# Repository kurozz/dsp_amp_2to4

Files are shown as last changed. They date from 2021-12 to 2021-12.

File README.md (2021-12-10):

DSP Amplifier - 2 inputs 4 outputs
Amplifier with DSP based on TPA3116D2 and ADAU1701 with 4 outputs and stereo input.

DSP programming can be done with SigmaStudio and needs an appropriate programmer.
How to program: https://daumemo.com/how-to-program-an-analog-devices-dsp/

Hackaday.io: https://hackaday.io/project/182993-dsp-amplifier-2-inputs-4-outputs
Project at PCBWAY (I get some credits if you buy the PCB from this link): https://www.pcbway.com/project/shareproject/DSP_Amplifier___2_inputs_4_outputs.html

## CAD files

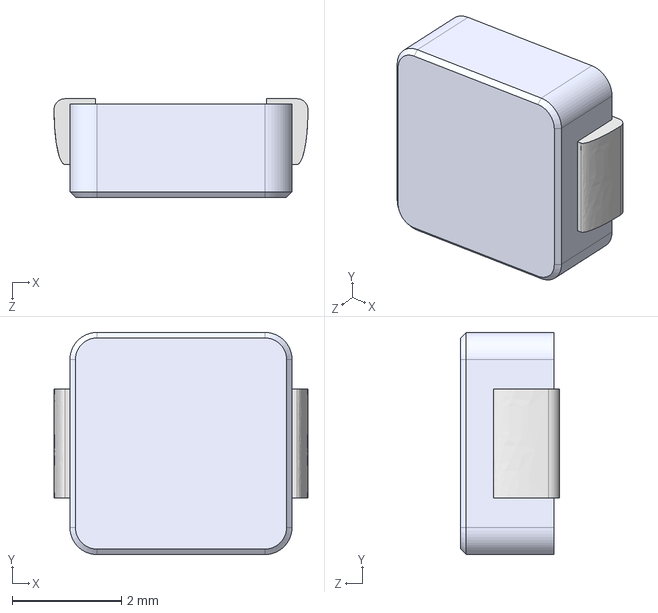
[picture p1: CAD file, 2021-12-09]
3D/WE_Inductor_4020.STEP
4.64 x 4.06 x 1.80 mm

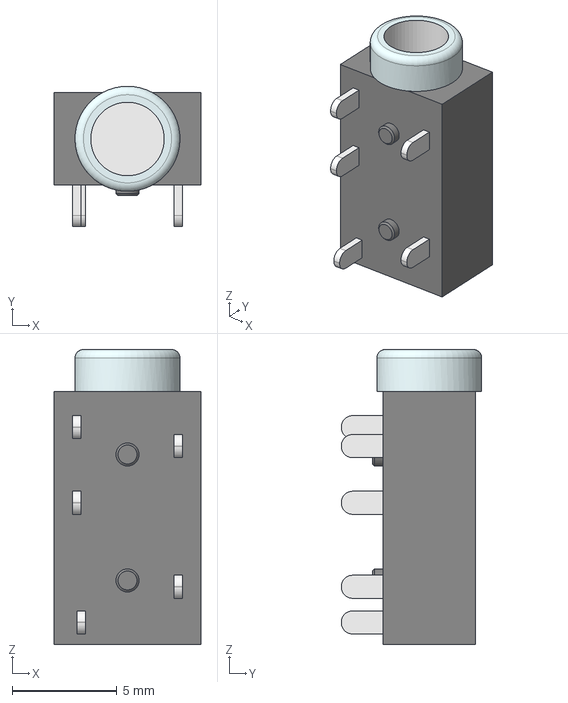
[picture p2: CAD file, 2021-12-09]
3D/PJ-3720.step
7.00 x 6.69 x 14.1 mm

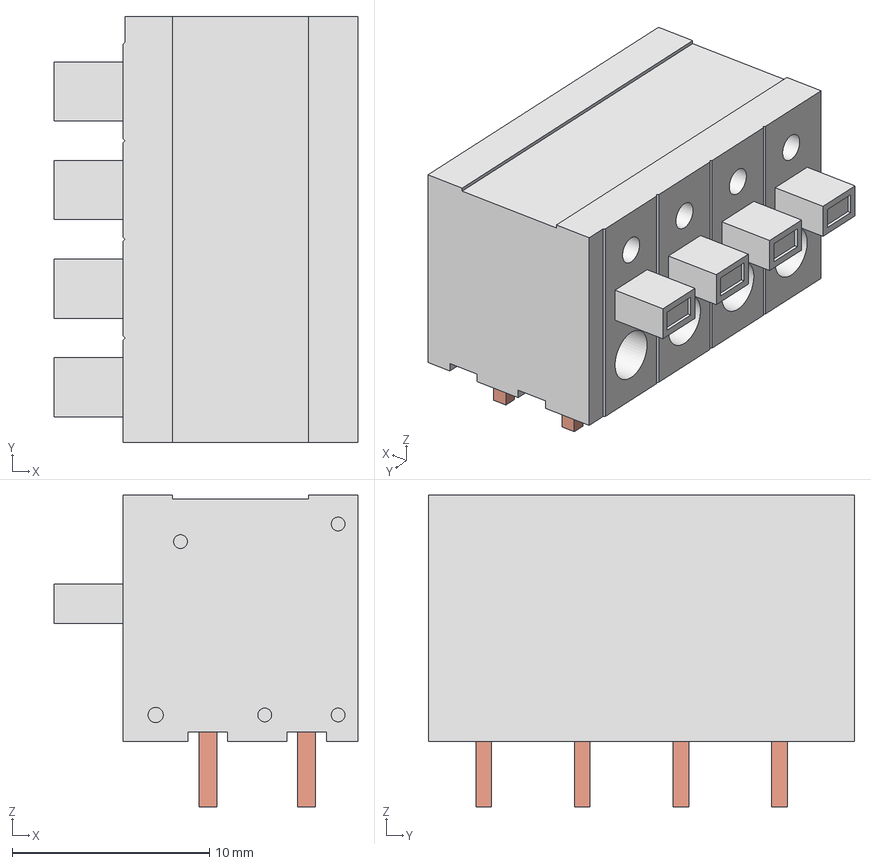
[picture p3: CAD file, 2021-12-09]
3D/KF211R.stp
15.4 x 21.6 x 15.8 mm

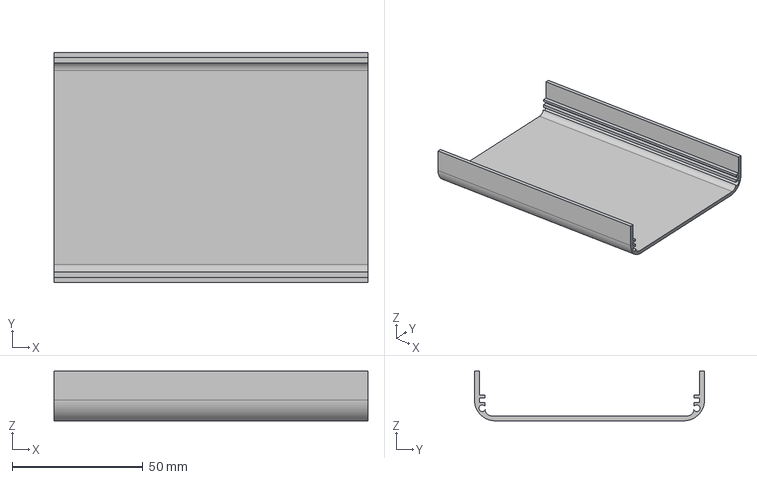
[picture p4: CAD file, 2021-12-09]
3D/aluminum_enclosure_88x38.step
120.0 x 88.0 x 19.0 mm

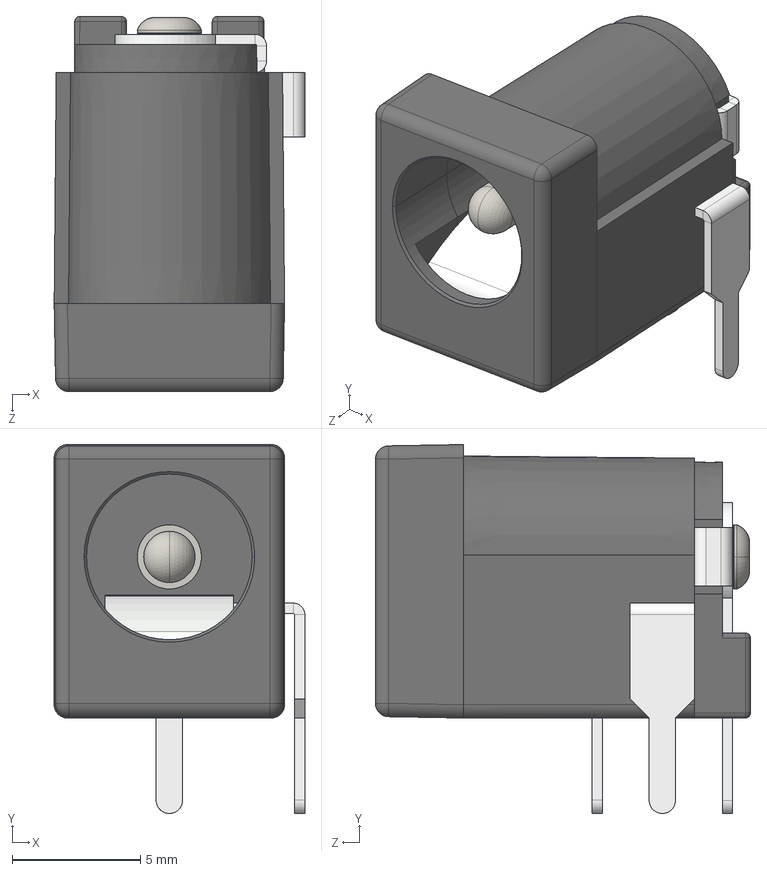
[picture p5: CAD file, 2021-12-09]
3D/DC Power Jack 5.5mm x 2.1mm.STEP
9.77 x 14.4 x 14.6 mm

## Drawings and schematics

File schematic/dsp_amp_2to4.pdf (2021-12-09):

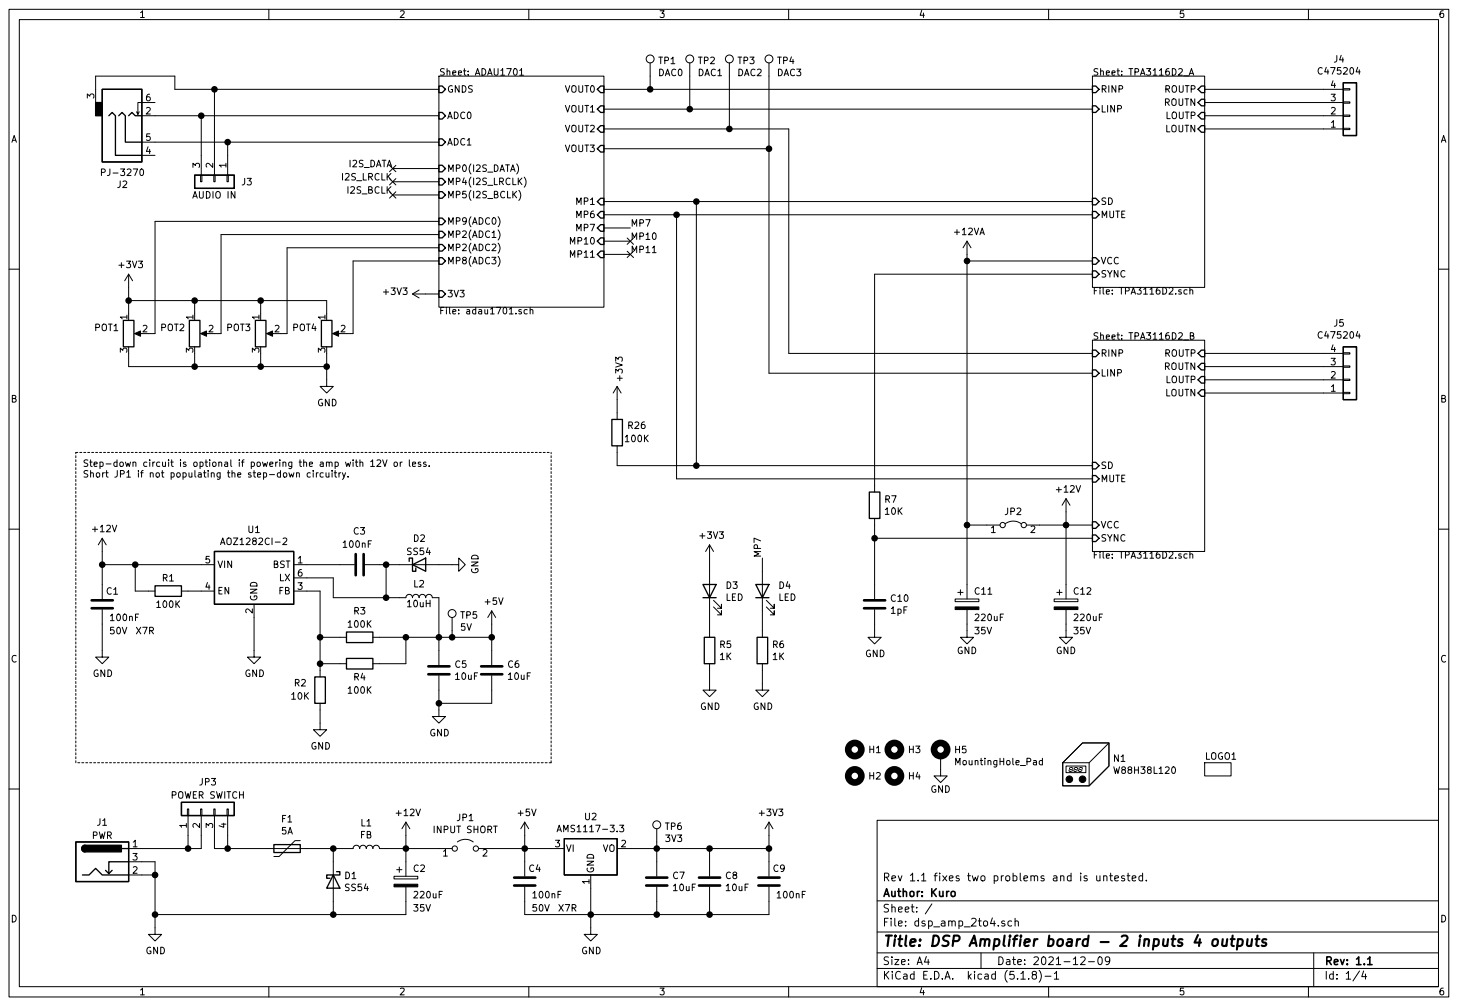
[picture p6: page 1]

File: TPA3116D2.sch SYNC MUTE

Step-down circuit is optional if powering the amp with 12V or less.
Short JP1 if not populating the step-down circuitry.

File: dsp_amp_2to4.sch Sheet: / Author: Kuro Rev 1.1 fixes two problems and is untested.

Id: 1/4 Title: DSP Amplifier board - 2 inputs 4 outputs

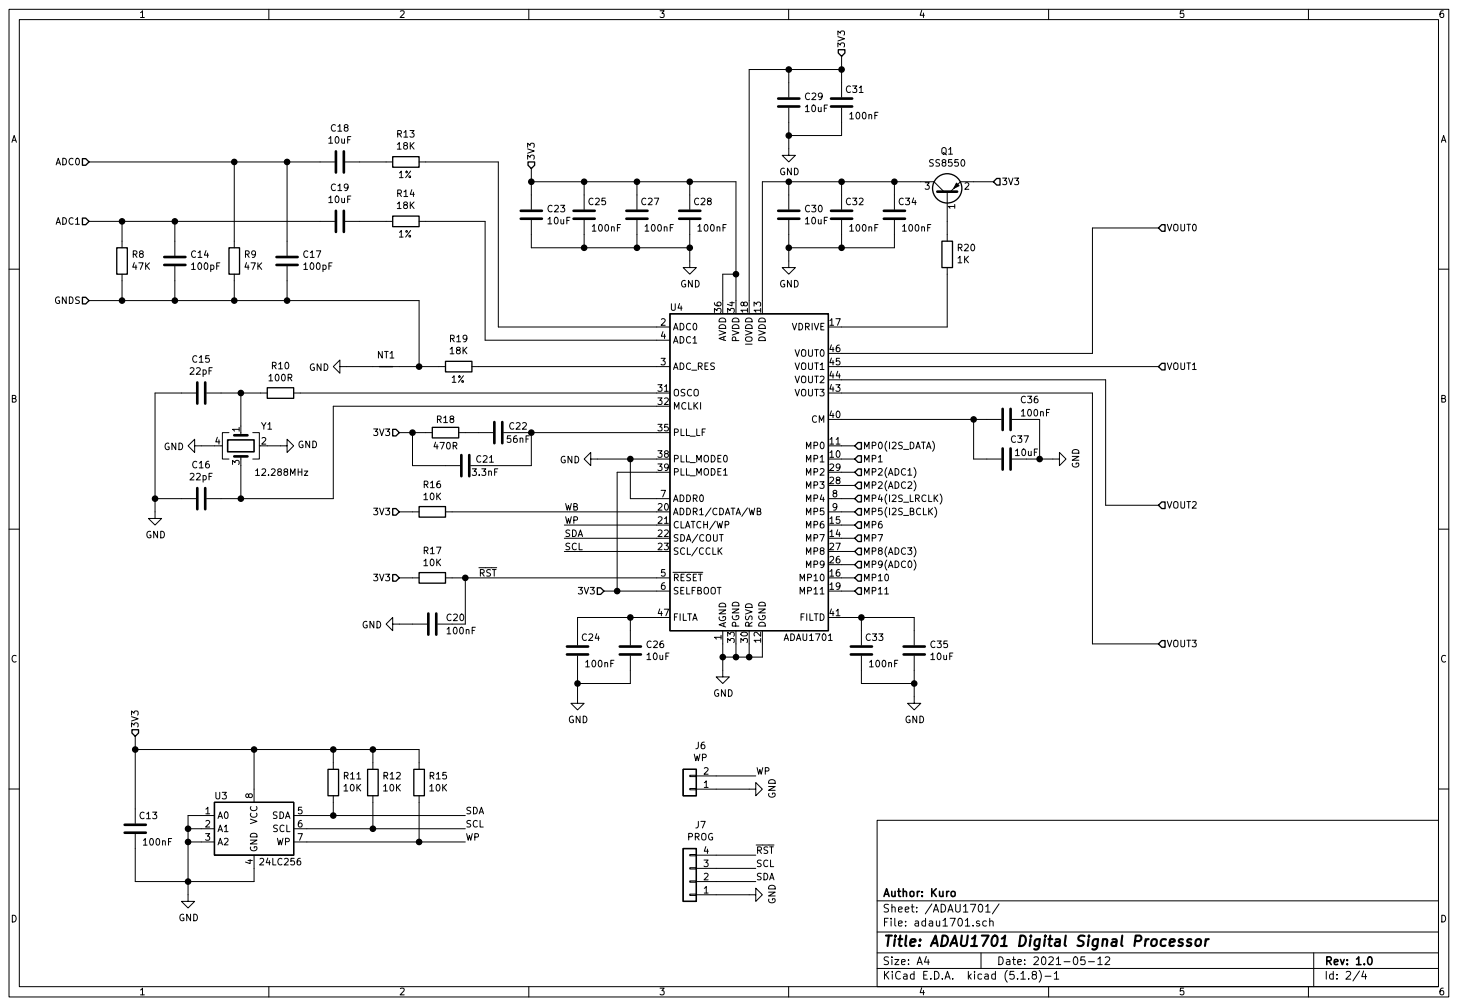
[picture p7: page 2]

Id: 2/4 Title: ADAU1701 Digital Signal Processor File: adau1701.sch Sheet: /ADAU1701/ Author: Kuro R11

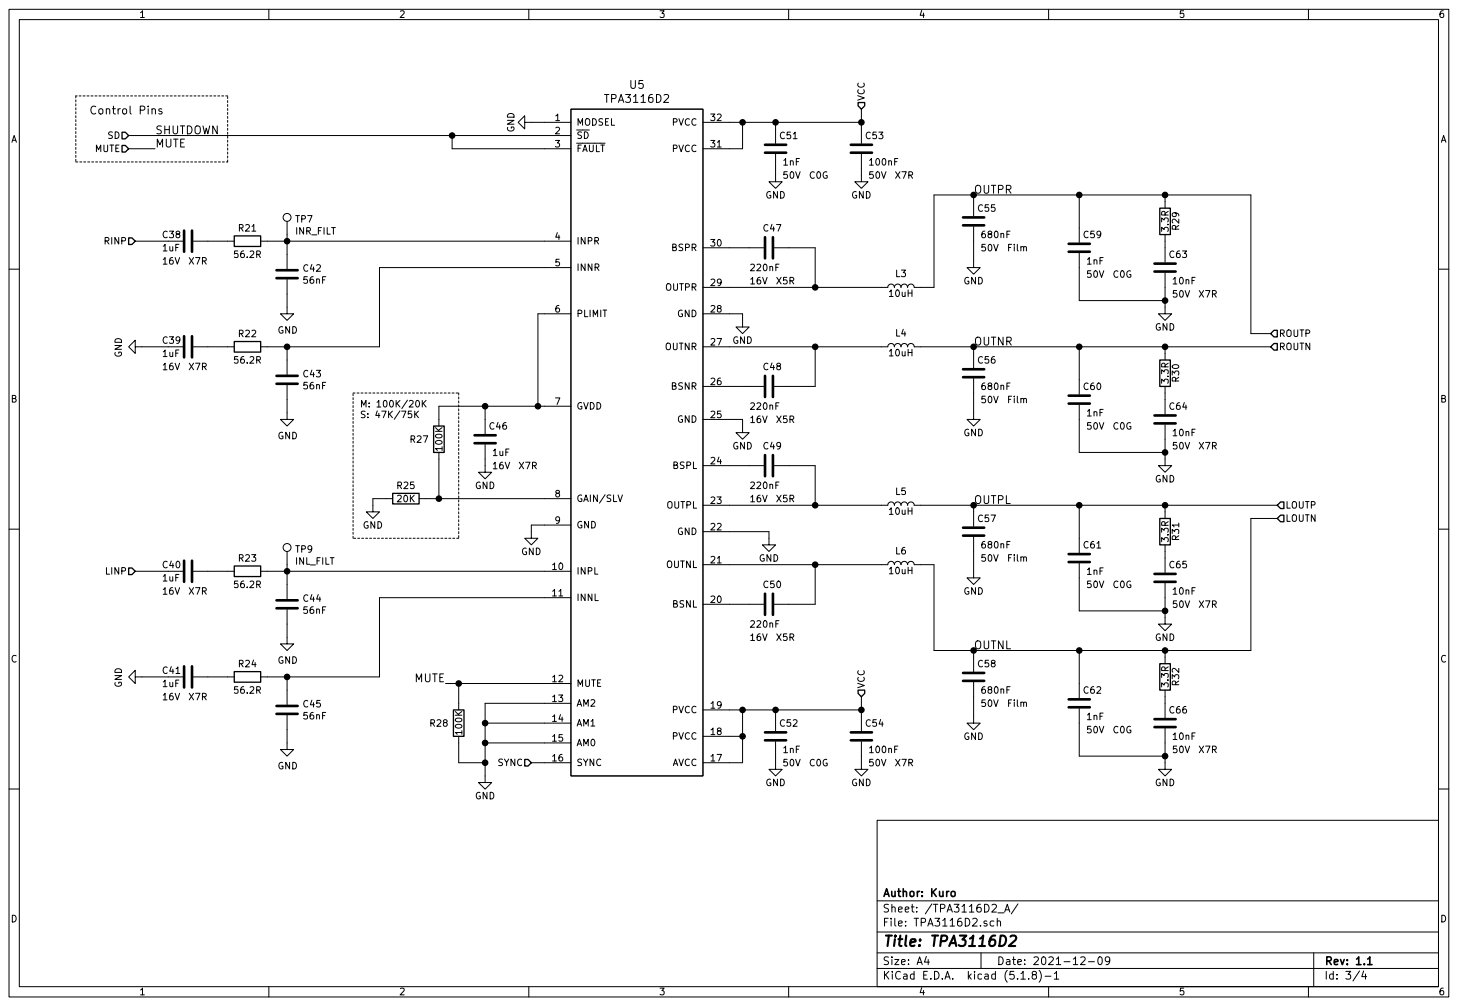
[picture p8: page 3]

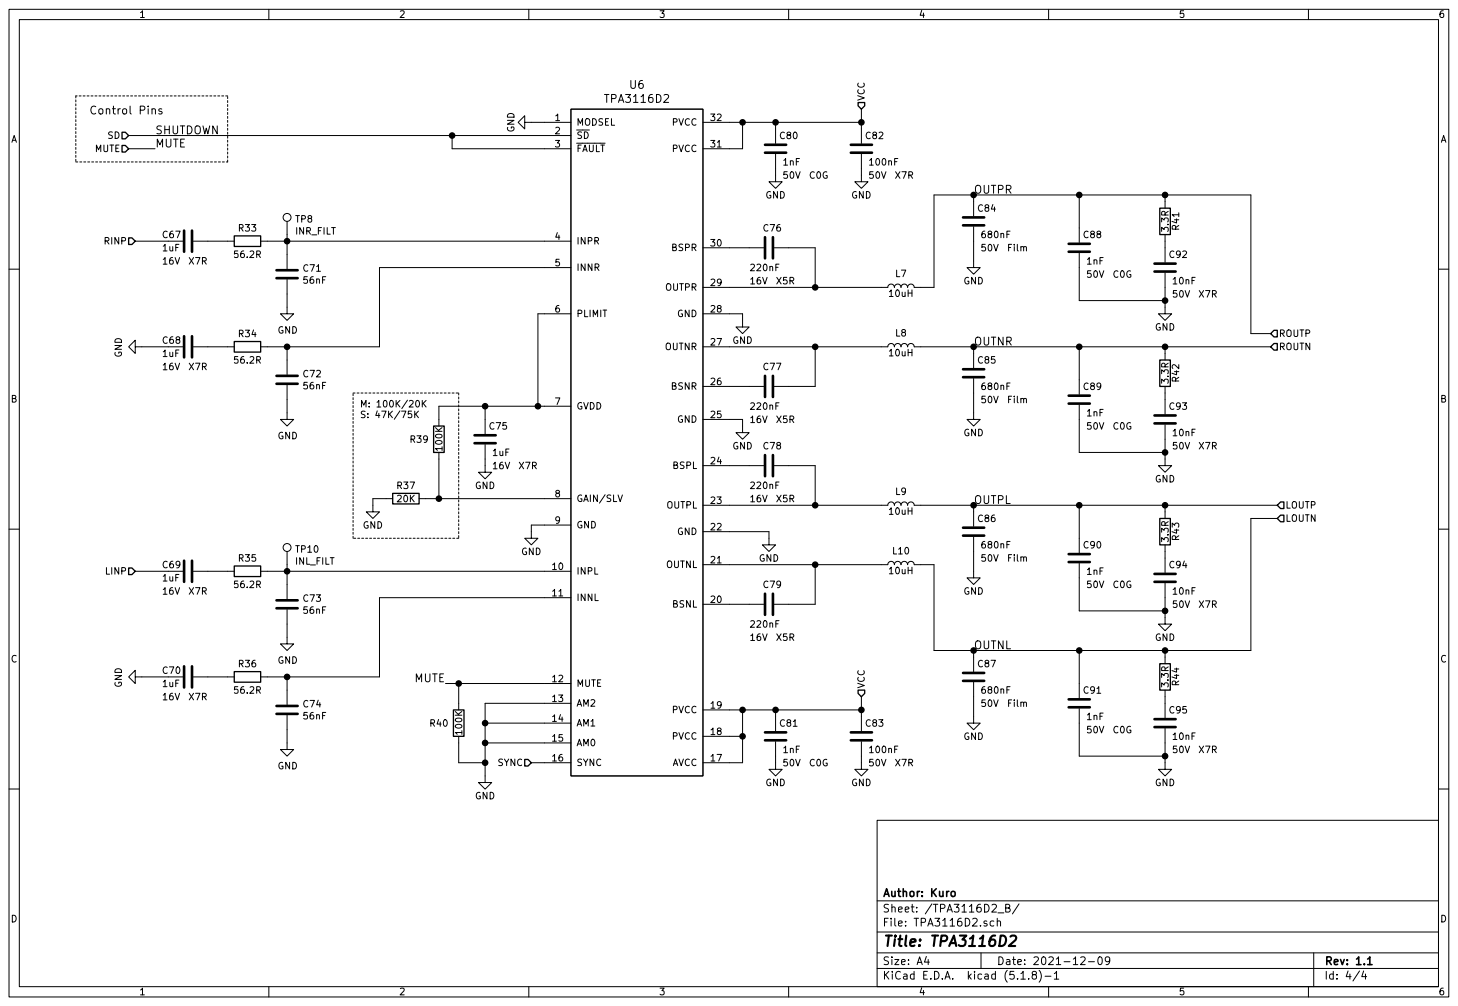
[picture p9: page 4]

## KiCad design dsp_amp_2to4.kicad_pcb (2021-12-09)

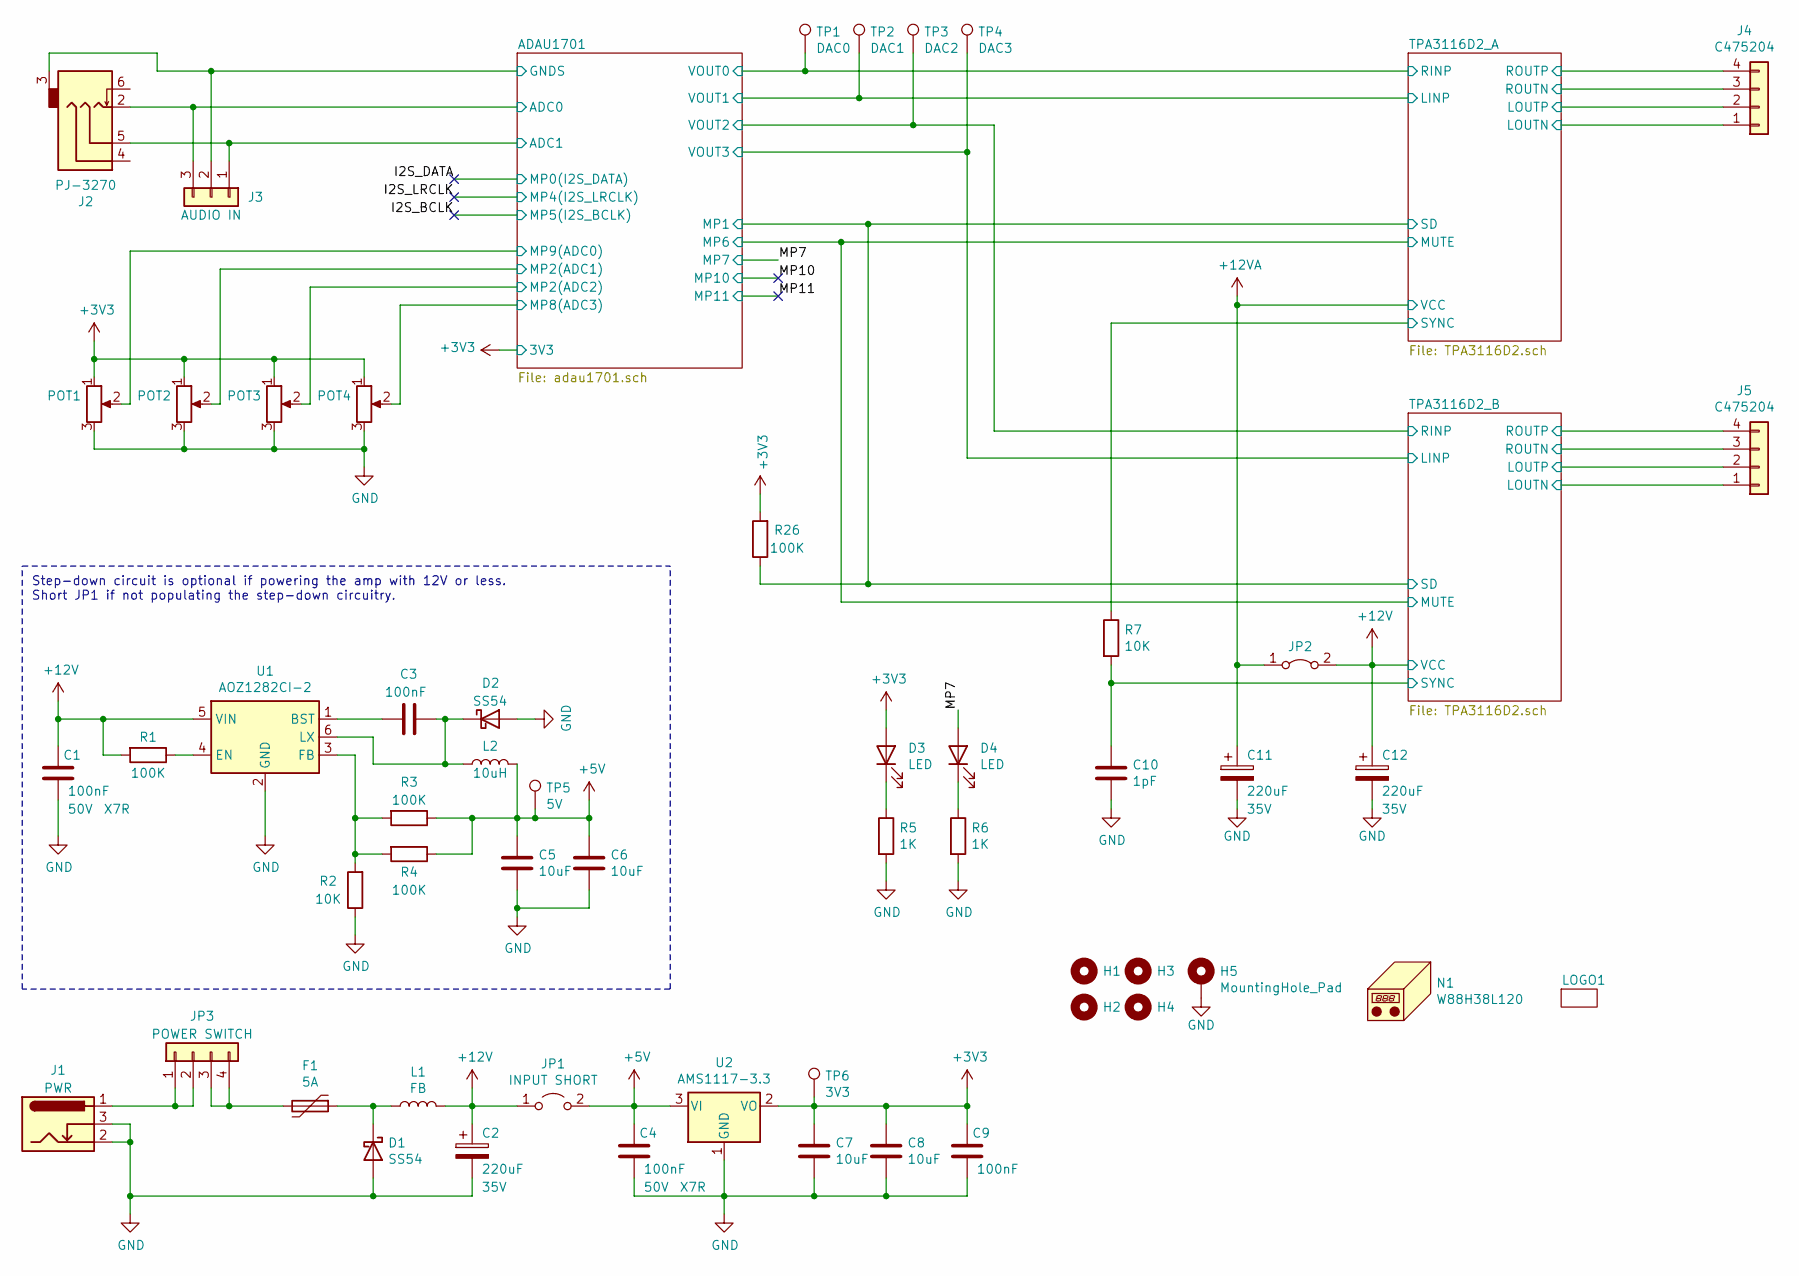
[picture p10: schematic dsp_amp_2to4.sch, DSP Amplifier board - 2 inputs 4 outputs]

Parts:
C1, C3, C4, C9: 100nF; C_0603_1608Metric; Rating X7R; Voltage 50V; LCSC Part Number C14663
C2, C11, C12: 220uF; CP_Radial_D8.0mm_P3.50mm; Voltage 35V; LCSC Part Number C433284
C5, C6, C7, C8: 10uF; C_0603_1608Metric; LCSC Part Number C85713
C10: 1pF; C_0603_1608Metric
D1, D2: SS54; D_SMA; LCSC Part Number C908681
D3, D4: LED; LED_D3.0mm; LCSC Part Number C710207
F1: 5A; Fuse_1206_3216Metric; LCSC Part Number C99541
H1, H2, H3, H4: MountingHole; MountingHole_3.2mm_M3
H5: MountingHole_Pad; MountingHole_3.2mm_M3_Pad_Via
J1: PWR; C381116; LCSC Part Number C381116
J2: PJ-3270; LCSC Part Number C381134
J3: JST XH-B3B; JST_XH_B3B-XH-A_1x03_P2.50mm_Vertical; LCSC Part Number C2316
J4, J5: C475204; LCSC Part Number C475204
JP1: INPUT SHORT; SolderJumper-2_P1.3mm_Open_TrianglePad1.0x1.5mm
JP2: Jumper Wire; R_Axial_DIN0204_L3.6mm_D1.6mm_P7.62mm_Horizontal
JP3: POWER SWITCH; JST_XH_B4B-XH-A_1x04_P2.50mm_Vertical
L1: FB; L_0805_2012Metric; LCSC Part Number C304323
L2: 10uH; L_6.3x6.3_H3; LCSC Part Number C207842
LOGO1: logo; shamiko
N1: W88H38L120; Aluminum_W88H38L120
POT1, POT2, POT3, POT4: JST XH-B3B; JST_XH_B3B-XH-A_1x03_P2.50mm_Vertical; LCSC Part Number C2316
R1, R3, R4, R26: 100K; R_0603_1608Metric; LCSC Part Number C14675
R2, R7: 10K; R_0603_1608Metric; LCSC Part Number C98220
R5, R6: 1K; R_0603_1608Metric; LCSC Part Number C22548
TP1: DAC0; TestPoint_THTPad_D1.0mm_Drill0.5mm
TP2: DAC1; TestPoint_THTPad_D1.0mm_Drill0.5mm
TP3: DAC2; TestPoint_THTPad_D1.0mm_Drill0.5mm
TP4: DAC3; TestPoint_THTPad_D1.0mm_Drill0.5mm
TP5: 5V; TestPoint_THTPad_D1.0mm_Drill0.5mm
TP6: 3V3; TestPoint_THTPad_D1.0mm_Drill0.5mm
U1: AOZ1282CI-2; SOT-23-6; LCSC Part Number C176766
U2: AMS1117-3.3; SOT-223-3_TabPin2; LCSC Part Number C347222

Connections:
+3V3: C7.1, C8.1, C9.1, D3.2 (A), POT1.1, POT2.1, POT3.1, POT4.1, R26.2, TP6.1, U2.2 (VO); also elsewhere on the board
+5V: C4.1, C5.1, C6.1, JP1.2 (B), L2.2, R3.1, R4.1, TP5.1, U2.3 (VI)
+12V: C1.1, C2.1, C12.1, JP1.1 (A), JP2.2 (B), L1.2, R1.2, U1.5 (VIN); also elsewhere on the board
+12VA: C11.1, JP2.1 (A); also elsewhere on the board
/ADAU1701/ADC0: J2.2, J3.3; also elsewhere on the board
/ADAU1701/ADC1: J2.5, J3.1; also elsewhere on the board
/ADAU1701/GNDS: J2.3, J3.2; also elsewhere on the board
/ADAU1701/MP1: R26.1; also elsewhere on the board
/ADAU1701/MP2(ADC1): POT2.2; also elsewhere on the board
/ADAU1701/MP2(ADC2): POT3.2; also elsewhere on the board
/ADAU1701/MP8(ADC3): POT4.2; also elsewhere on the board
/ADAU1701/MP9(ADC0): POT1.2; also elsewhere on the board
/MP7: D4.2 (A); also elsewhere on the board
/TPA3116D2_A/LINP: TP2.1; also elsewhere on the board
/TPA3116D2_A/LOUTN: J4.1; also elsewhere on the board
/TPA3116D2_A/LOUTP: J4.2; also elsewhere on the board
/TPA3116D2_A/RINP: TP1.1; also elsewhere on the board
/TPA3116D2_A/ROUTN: J4.3; also elsewhere on the board
/TPA3116D2_A/ROUTP: J4.4; also elsewhere on the board
/TPA3116D2_A/SYNC: R7.1; also elsewhere on the board
/TPA3116D2_B/LINP: TP4.1; also elsewhere on the board
/TPA3116D2_B/LOUTN: J5.1; also elsewhere on the board
/TPA3116D2_B/LOUTP: J5.2; also elsewhere on the board
/TPA3116D2_B/RINP: TP3.1; also elsewhere on the board
/TPA3116D2_B/ROUTN: J5.3; also elsewhere on the board
/TPA3116D2_B/ROUTP: J5.4; also elsewhere on the board
/TPA3116D2_B/SYNC: C10.1, R7.2; also elsewhere on the board
GND: C1.2, C2.2, C4.2, C5.2, C6.2, C7.2, C8.2, C9.2, C10.2, C11.2, C12.2, D1.2 (A), D2.2 (A), H5.1, J1.2, J1.3, POT1.3, POT2.3, POT3.3, POT4.3, R2.1, R5.2, R6.2, U1.2 (GND), U2.1 (GND); also elsewhere on the board
unnamed: C3.1, U1.1 (BST)
unnamed: C3.2, D2.1 (K), L2.1, U1.6 (LX)
unnamed: D1.1 (K), F1.1, L1.1
unnamed: D3.1 (K), R5.1
unnamed: D4.1 (K), R6.1
unnamed: F1.2, JP3.3, JP3.4
unnamed: J1.1, JP3.1, JP3.2
unnamed: R1.1, U1.4 (EN)
unnamed: R2.2, R3.2, R4.2, U1.3 (FB)

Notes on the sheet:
Step-down circuit is optional if powering the amp with 12V or less. Short JP1 if not populating the step-down circuitry.

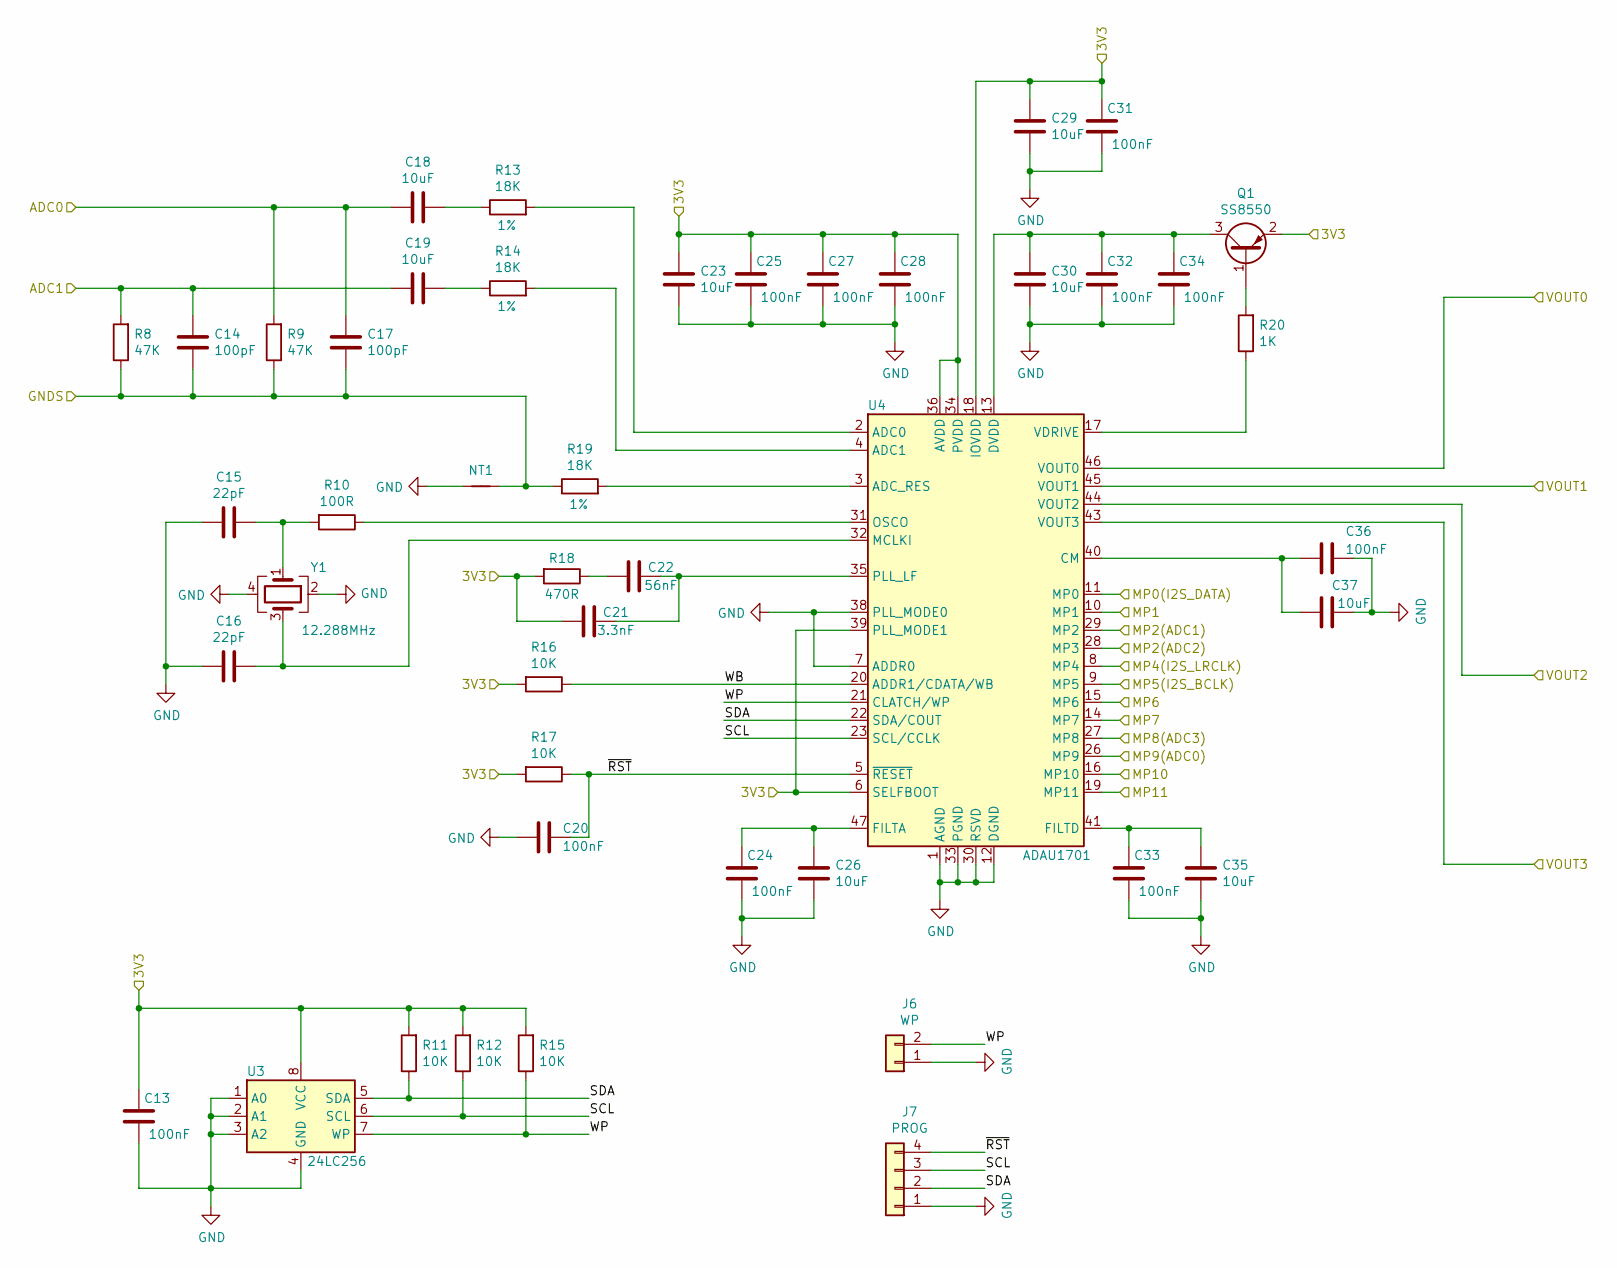
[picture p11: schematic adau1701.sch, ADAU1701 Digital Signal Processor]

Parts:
C13, C20, C24, C25, C27, C28, C31, C32, C33, C34, C36: 100nF; C_0603_1608Metric; Rating X7R; Voltage 50V; LCSC Part Number C14663
C14, C17: 100pF; C_0603_1608Metric; LCSC Part Number C14665
C15, C16: 22pF; C_0603_1608Metric; LCSC Part Number C105620
C18, C19, C23, C26, C29, C30, C35, C37: 10uF; C_0603_1608Metric; LCSC Part Number C85713
C21: 3.3nF; C_0603_1608Metric; LCSC Part Number C107088
C22: 56nF; C_0603_1608Metric; LCSC Part Number C282072
J6: WP; PinHeader_1x02_P2.54mm_Vertical
J7: PROG; PinHeader_1x04_P2.54mm_Vertical
NT1: Net-Tie_2; NetTie-2_SMD_Pad0.5mm
Q1: SS8550; SOT-23; LCSC Part Number C545534
R8, R9: 47K; R_0603_1608Metric; LCSC Part Number C105579
R10: 100R; R_0603_1608Metric; LCSC Part Number C105588
R11, R12, R15, R16, R17: 10K; R_0603_1608Metric; LCSC Part Number C98220
R13, R14, R19: 18K; R_0603_1608Metric; Tolerance 1%; LCSC Part Number C114610
R18: 470R; R_0603_1608Metric; LCSC Part Number C114669
R20: 1K; R_0603_1608Metric; LCSC Part Number C22548
U3: 24LC256; SOIC-8_3.9x4.9mm_P1.27mm; LCSC Part Number C5458
U4: ADAU1701; LQFP-48_7x7mm_P0.5mm; LCSC Part Number C389590
Y1: 12.288MHz; Crystal_SMD_SeikoEpson_FA238-4Pin_3.2x2.5mm; LCSC Part Number C389826

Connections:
+3V3: C13.1, C21.2, C23.1, C25.1, C27.1, C28.1, C29.1, C31.1, Q1.2 (E), R11.2, R12.2, R15.2, R16.2, R17.2, R18.2, U3.8 (VCC), U4.6 (SELFBOOT), U4.18 (IOVDD), U4.34 (PVDD), U4.36 (AVDD), U4.39 (PLL_MODE1), U4.48 (AVDD); also elsewhere on the board
/ADAU1701/ADC0: C17.2, C18.1, R9.2; also elsewhere on the board
/ADAU1701/ADC1: C14.2, C19.1, R8.2; also elsewhere on the board
/ADAU1701/GNDS: C14.1, C17.1, NT1.2, R8.1, R9.1, R19.1; also elsewhere on the board
/ADAU1701/MP1: U4.10 (MP1); also elsewhere on the board
/ADAU1701/MP2(ADC1): U4.29 (MP2); also elsewhere on the board
/ADAU1701/MP2(ADC2): U4.28 (MP3); also elsewhere on the board
/ADAU1701/MP6: U4.15 (MP6); also elsewhere on the board
/ADAU1701/MP8(ADC3): U4.27 (MP8); also elsewhere on the board
/ADAU1701/MP9(ADC0): U4.26 (MP9); also elsewhere on the board
/ADAU1701/SCL: J7.3, R12.1, U3.6 (SCL), U4.23 (SCL/CCLK)
/ADAU1701/SDA: J7.2, R11.1, U3.5 (SDA), U4.22 (SDA/COUT)
/ADAU1701/WB: R16.1, U4.20 (ADDR1/CDATA/WB)
/ADAU1701/WP: J6.2, R15.1, U3.7 (WP), U4.21 (CLATCH/WP)
/ADAU1701/~RST: C20.1, J7.4, R17.1, U4.5 (~RESET)
/I2S_BCLK: U4.9 (MP5)
/I2S_DATA: U4.11 (MP0)
/I2S_LRCLK: U4.8 (MP4)
/MP7: U4.14 (MP7); also elsewhere on the board
/MP10: U4.16 (MP10)
/MP11: U4.19 (MP11)
/TPA3116D2_A/LINP: U4.45 (VOUT1); also elsewhere on the board
/TPA3116D2_A/RINP: U4.46 (VOUT0); also elsewhere on the board
/TPA3116D2_B/LINP: U4.43 (VOUT3); also elsewhere on the board
/TPA3116D2_B/RINP: U4.44 (VOUT2); also elsewhere on the board
GND: C13.2, C15.1, C16.1, C20.2, C23.2, C24.2, C25.2, C26.2, C27.2, C28.2, C29.2, C30.2, C31.2, C32.2, C33.2, C34.2, C35.2, C36.1, C37.1, J6.1, J7.1, NT1.1, U3.1 (A0), U3.2 (A1), U3.3 (A2), U3.4 (GND), U4.1 (AGND), U4.7 (ADDR0), U4.12 (DGND), U4.25 (DGND), U4.30 (RSVD), U4.33 (PGND), U4.37 (AGND), U4.38 (PLL_MODE0), U4.42 (AGND), Y1.2, Y1.4; also elsewhere on the board
unnamed: C15.2, R10.2, Y1.1
unnamed: C16.2, U4.32 (MCLKI), Y1.3
unnamed: C18.2, R13.1
unnamed: C19.2, R14.1
unnamed: C21.1, C22.1, U4.35 (PLL_LF)
unnamed: C22.2, R18.1
unnamed: C24.1, C26.1, U4.47 (FILTA)
unnamed: C30.1, C32.1, C34.1, Q1.3 (C), U4.13 (DVDD), U4.24 (DVDD)
unnamed: C33.1, C35.1, U4.41 (FILTD)
unnamed: C36.2, C37.2, U4.40 (CM)
unnamed: Q1.1 (B), R20.2
unnamed: R10.1, U4.31 (OSCO)
unnamed: R13.2, U4.2 (ADC0)
unnamed: R14.2, U4.4 (ADC1)
unnamed: R19.2, U4.3 (ADC_RES)
unnamed: R20.1, U4.17 (VDRIVE)

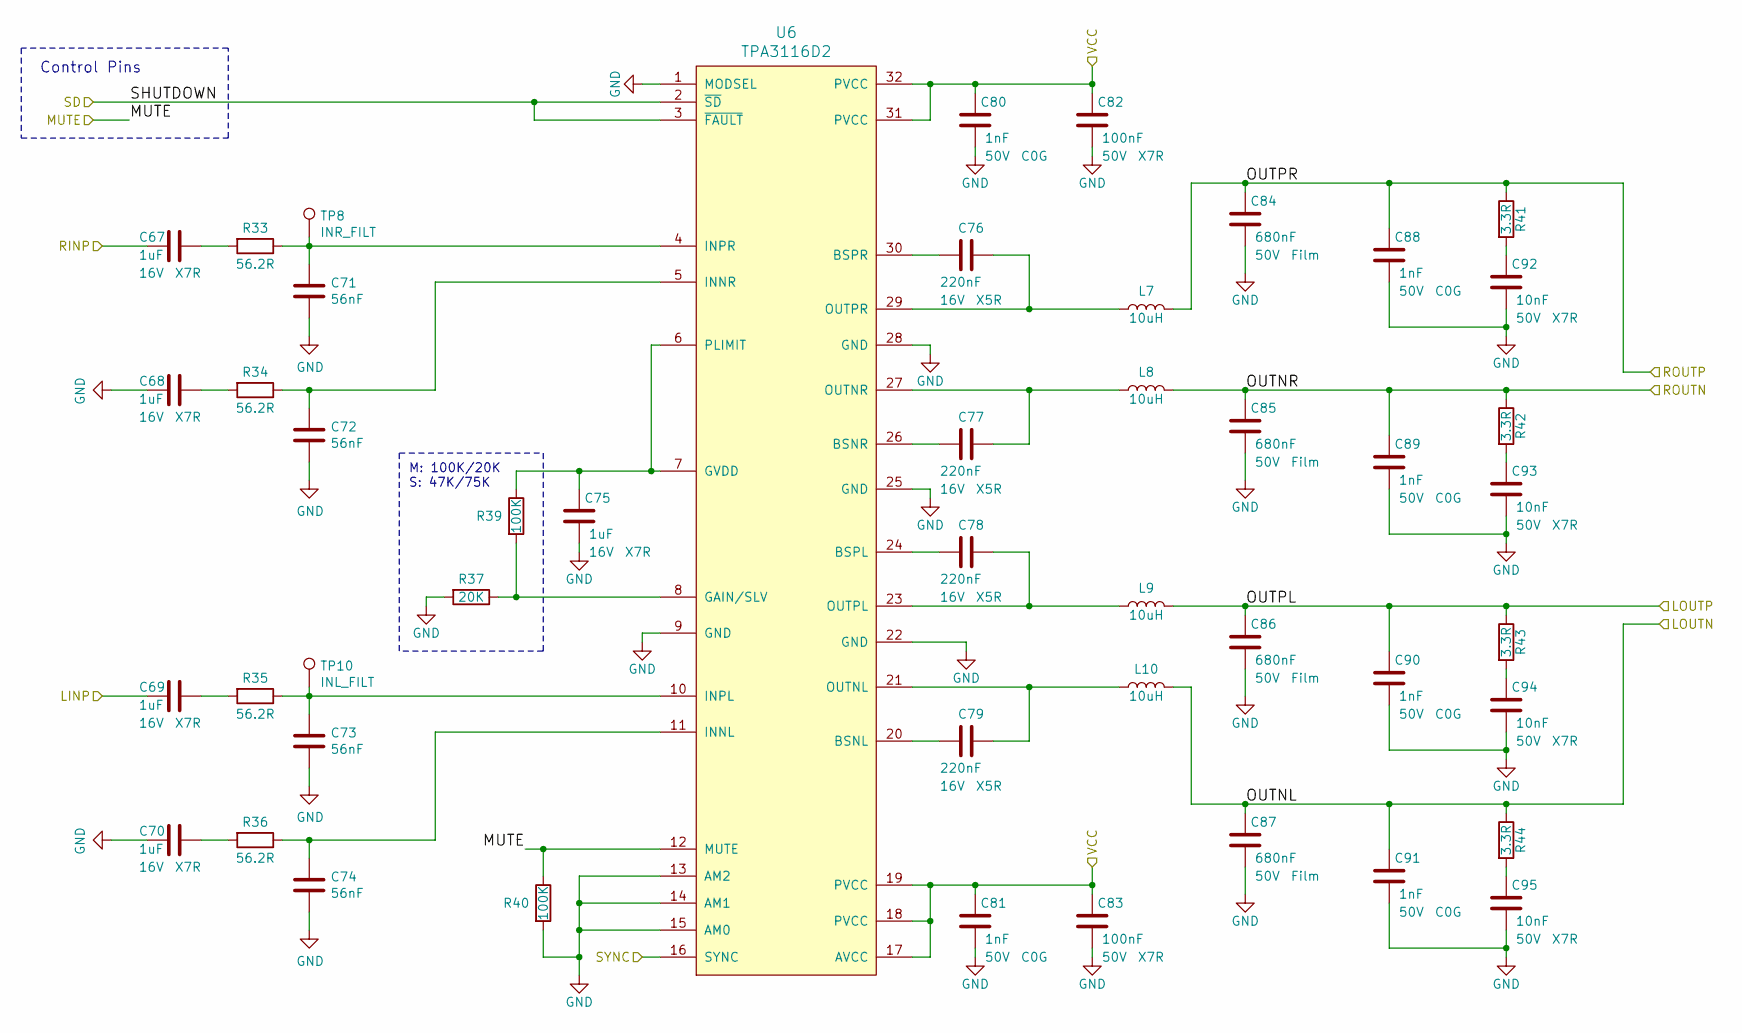
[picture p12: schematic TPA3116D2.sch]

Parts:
C38, C39, C40, C41, C46: 1uF; C_0603_1608Metric; Rating X7R; Voltage 16V; LCSC Part Number C59782
C42, C43, C44, C45: 56nF; C_0603_1608Metric; LCSC Part Number C282072
C47, C48, C49, C50: 220nF; C_0603_1608Metric; Rating X5R; Voltage 16V; LCSC Part Number C21120
C51, C52, C59, C60, C61, C62: 1nF; C_0603_1608Metric; Rating C0G; Voltage 50V; LCSC Part Number C163508
C53, C54: 100nF; C_0603_1608Metric; Rating X7R; Voltage 50V; LCSC Part Number C14663
C55, C56, C57, C58: 680nF; C_Rect_L7.0mm_W4.5mm_P5.00mm; Rating Film; Voltage 50V; LCSC Part Number C280298
C63, C64, C65, C66: 10nF; C_0603_1608Metric; Rating X7R; Voltage 50V; LCSC Part Number C107059
L3, L4, L5, L6: 10uH; L_6.3x6.3_H3; LCSC Part Number C207842
R21, R22, R23, R24: 56.2R; R_0603_1608Metric; LCSC Part Number C137698
R25: 20K; R_0603_1608Metric; LCSC Part Number C105575
R27, R28: 100K; R_0603_1608Metric; LCSC Part Number C14675
R29, R30, R31, R32: 3.3R; R_0603_1608Metric; LCSC Part Number C137725
TP7: INR_FILT; TestPoint_Pad_D1.0mm
TP9: INL_FILT; TestPoint_Pad_D1.0mm
U5: TPA3116D2; HTSSOP-32-1EP_6.1x11mm_P0.65mm_EP5.2x11mm_Mask4.11x4.36mm_T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; LCSC Part Number C50144

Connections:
+12VA: C51.1, C52.1, C53.1, C54.1, U5.17 (AVCC), U5.18 (PVCC), U5.19 (PVCC), U5.31 (PVCC), U5.32 (PVCC); also elsewhere on the board
/ADAU1701/MP1: U5.2 (~SD), U5.3 (~FAULT); also elsewhere on the board
/ADAU1701/MP6: R28.1, U5.12 (MUTE); also elsewhere on the board
/TPA3116D2_A/LINP: C40.2; also elsewhere on the board
/TPA3116D2_A/LOUTN: C58.1, C62.1, L6.2, R32.1; also elsewhere on the board
/TPA3116D2_A/LOUTP: C57.1, C61.1, L5.2, R31.1; also elsewhere on the board
/TPA3116D2_A/RINP: C38.2; also elsewhere on the board
/TPA3116D2_A/ROUTN: C56.1, C60.1, L4.2, R30.1; also elsewhere on the board
/TPA3116D2_A/ROUTP: C55.1, C59.1, L3.2, R29.1; also elsewhere on the board
/TPA3116D2_A/SYNC: U5.16 (SYNC); also elsewhere on the board
GND: C39.2, C41.2, C42.2, C43.2, C44.2, C45.2, C46.2, C51.2, C52.2, C53.2, C54.2, C55.2, C56.2, C57.2, C58.2, C59.2, C60.2, C61.2, C62.2, C63.2, C64.2, C65.2, C66.2, R25.2, R28.2, U5.1 (MODSEL), U5.9 (GND), U5.13 (AM2), U5.14 (AM1), U5.15 (AM0), U5.22 (GND), U5.25 (GND), U5.28 (GND), U5.33 (GND); also elsewhere on the board
unnamed: C38.1, R21.2
unnamed: C39.1, R22.2
unnamed: C40.1, R23.2
unnamed: C41.1, R24.2
unnamed: C42.1, R21.1, TP7.1, U5.4 (INPR)
unnamed: C43.1, R22.1, U5.5 (INNR)
unnamed: C44.1, R23.1, TP9.1, U5.10 (INPL)
unnamed: C45.1, R24.1, U5.11 (INNL)
unnamed: C46.1, R27.1, U5.6 (PLIMIT), U5.7 (GVDD)
unnamed: C47.1, L3.1, U5.29 (OUTPR)
unnamed: C47.2, U5.30 (BSPR)
unnamed: C48.1, L4.1, U5.27 (OUTNR)
unnamed: C48.2, U5.26 (BSNR)
unnamed: C49.1, L5.1, U5.23 (OUTPL)
unnamed: C49.2, U5.24 (BSPL)
unnamed: C50.1, L6.1, U5.21 (OUTNL)
unnamed: C50.2, U5.20 (BSNL)
unnamed: C63.1, R29.2
unnamed: C64.1, R30.2
unnamed: C65.1, R31.2
unnamed: C66.1, R32.2
unnamed: R25.1, R27.2, U5.8 (GAIN/SLV)

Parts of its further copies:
C67, C68, C69, C70, C75: 1uF; C_0603_1608Metric; Rating X7R; Voltage 16V; LCSC Part Number C59782
C71, C72, C73, C74: 56nF; C_0603_1608Metric; LCSC Part Number C282072
C76, C77, C78, C79: 220nF; C_0603_1608Metric; Rating X5R; Voltage 16V; LCSC Part Number C21120
C80, C81, C88, C89, C90, C91: 1nF; C_0603_1608Metric; Rating C0G; Voltage 50V; LCSC Part Number C163508
C82, C83: 100nF; C_0603_1608Metric; Rating X7R; Voltage 50V; LCSC Part Number C14663
C84, C85, C86, C87: 680nF; C_Rect_L7.0mm_W4.5mm_P5.00mm; Rating Film; Voltage 50V; LCSC Part Number C280298
C92, C93, C94, C95: 10nF; C_0603_1608Metric; Rating X7R; Voltage 50V; LCSC Part Number C107059
L7, L8, L9, L10: 10uH; L_6.3x6.3_H3; LCSC Part Number C207842
R33, R34, R35, R36: 56.2R; R_0603_1608Metric; LCSC Part Number C137698
R37: 20K; R_0603_1608Metric; LCSC Part Number C105575
R39, R40: 100K; R_0603_1608Metric; LCSC Part Number C14675
R41, R42, R43, R44: 3.3R; R_0603_1608Metric; LCSC Part Number C137725
TP8: INR_FILT; TestPoint_Pad_D1.0mm
TP10: INL_FILT; TestPoint_Pad_D1.0mm
U6: TPA3116D2; HTSSOP-32-1EP_6.1x11mm_P0.65mm_EP5.2x11mm_Mask4.11x4.36mm_T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; LCSC Part Number C50144

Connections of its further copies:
+12V: C80.1, C81.1, C82.1, C83.1, U6.17 (AVCC), U6.18 (PVCC), U6.19 (PVCC), U6.31 (PVCC), U6.32 (PVCC); also elsewhere on the board
/ADAU1701/MP1: U6.2 (~SD), U6.3 (~FAULT); also elsewhere on the board
/ADAU1701/MP6: R40.1, U6.12 (MUTE); also elsewhere on the board
/TPA3116D2_B/LINP: C69.2; also elsewhere on the board
/TPA3116D2_B/LOUTN: C87.1, C91.1, L10.2, R44.1; also elsewhere on the board
/TPA3116D2_B/LOUTP: C86.1, C90.1, L9.2, R43.1; also elsewhere on the board
/TPA3116D2_B/RINP: C67.2; also elsewhere on the board
/TPA3116D2_B/ROUTN: C85.1, C89.1, L8.2, R42.1; also elsewhere on the board
/TPA3116D2_B/ROUTP: C84.1, C88.1, L7.2, R41.1; also elsewhere on the board
/TPA3116D2_B/SYNC: U6.16 (SYNC); also elsewhere on the board
GND: C68.2, C70.2, C71.2, C72.2, C73.2, C74.2, C75.2, C80.2, C81.2, C82.2, C83.2, C84.2, C85.2, C86.2, C87.2, C88.2, C89.2, C90.2, C91.2, C92.2, C93.2, C94.2, C95.2, R37.2, R40.2, U6.1 (MODSEL), U6.9 (GND), U6.13 (AM2), U6.14 (AM1), U6.15 (AM0), U6.22 (GND), U6.25 (GND), U6.28 (GND), U6.33 (GND); also elsewhere on the board
unnamed: C67.1, R33.2
unnamed: C68.1, R34.2
unnamed: C69.1, R35.2
unnamed: C70.1, R36.2
unnamed: C71.1, R33.1, TP8.1, U6.4 (INPR)
unnamed: C72.1, R34.1, U6.5 (INNR)
unnamed: C73.1, R35.1, TP10.1, U6.10 (INPL)
unnamed: C74.1, R36.1, U6.11 (INNL)
unnamed: C75.1, R39.1, U6.6 (PLIMIT), U6.7 (GVDD)
unnamed: C76.1, L7.1, U6.29 (OUTPR)
unnamed: C76.2, U6.30 (BSPR)
unnamed: C77.1, L8.1, U6.27 (OUTNR)
unnamed: C77.2, U6.26 (BSNR)
unnamed: C78.1, L9.1, U6.23 (OUTPL)
unnamed: C78.2, U6.24 (BSPL)
unnamed: C79.1, L10.1, U6.21 (OUTNL)
unnamed: C79.2, U6.20 (BSNL)
unnamed: C92.1, R41.2
unnamed: C93.1, R42.2
unnamed: C94.1, R43.2
unnamed: C95.1, R44.2
unnamed: R37.1, R39.2, U6.8 (GAIN/SLV)

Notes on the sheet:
Control Pins
M: 100K/20K S: 47K/75K

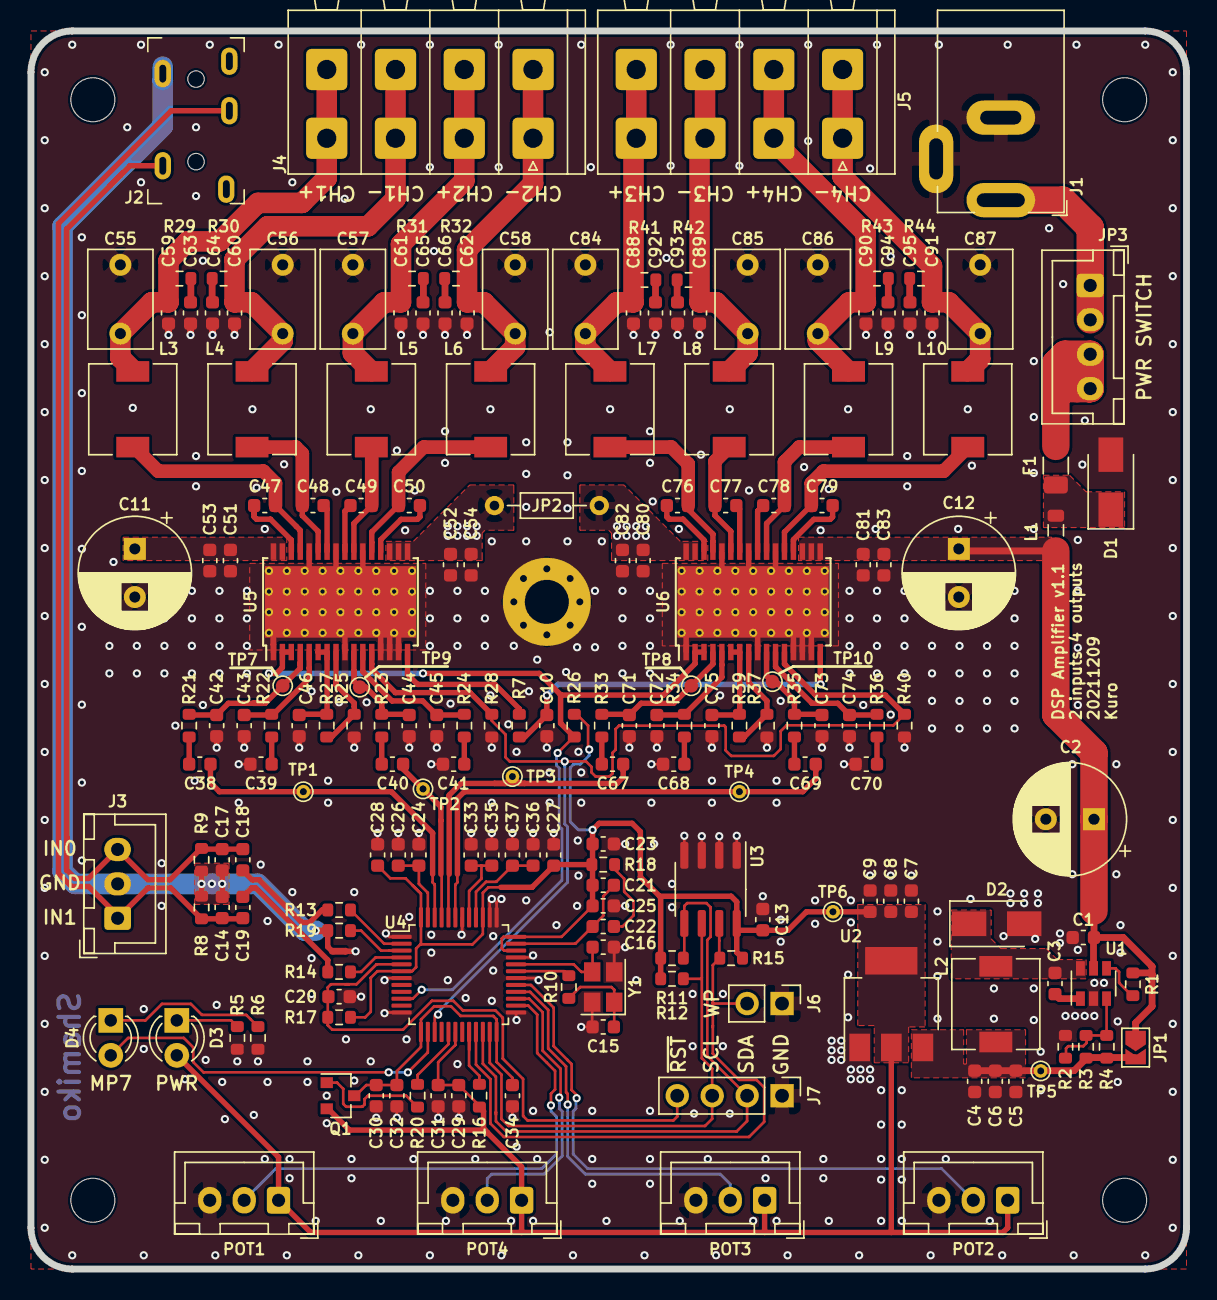
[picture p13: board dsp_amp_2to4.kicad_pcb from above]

Board: 2 copper layers, 84.0 x 90.0 mm, 193 parts (1 on the bottom side), 103 nets.
